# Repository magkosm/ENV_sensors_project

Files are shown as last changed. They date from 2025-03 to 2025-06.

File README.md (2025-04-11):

**Date**: 10/2024 - 01/2025  
**Author**: Robin GORIUS  
***Prelimenery Translations*** Michail Magkos
***PCB desing*** Enrique Hernando

These sensors were initially created to measure environmental variables in the Mars Desert Research Station in Utah for the CoreData set.  
As they are meant to be used by French students from future MDRS crews, a lot of documentation and code comments are in French.  

The development was done by Robin GORIUS over the course of 4 months. The sensors are far from perfect but could be considered as functioning prototypes for futur developpment.  
The main issue is the electrical assembly, which should be reduced to PCB soldering.  
Another improvement for easier use would be to shift the data exchange protocol from HTTP to MQTT and make the sensors go to sleep when not measuring.  
This change could enable the sensors to run on a battery for easier installation and integration with Home Assistant.  

sensor render

The sensors are equipped with 5 sensors and are able to measure the following variables:  

```
Temperature in °C  
Humidity in %  
Luminosity (Infrared, Visible, Total) in Lux  
Pressure in Pa  
CO2 levels in ppm  
VOC levels (unitless)  
```

The sensors are programmed to collect data every second and are asked by the collecting server to send their data every 30 seconds.  

The code for the sensor is quite versatile as it's written with well-separated classes.  
**WARNING**: Please note that the network manager implemented in the sensors isn't the most secure, as the SSIDs and passwords are stored directly in the ESP32 file system in a `.txt` file.  

The code for the collecting server is a bit messier, especially the part in charge of the graphs. This is due to the nature of the initial application not enabling the system to access online libraries.  

For further information on the use of the sensors, please check the user manual (French only for now, sorry!):  
[Manual](Manual/User_manual.pdf)  

Check out the CAD files in the [CAD folder](Mechanical_design/CAD/). Please note that the design was made with Fusion 360, and the `.step` file may present unwanted defects.  

The build information is briefly described in the [Build instructions](Electronics/Build_instructions.txt). The document is quite short but provides guidelines on how the assembly was designed. 

**Possible Future Implementations**:
- Add a Bluetooth scan to count nearby devices.

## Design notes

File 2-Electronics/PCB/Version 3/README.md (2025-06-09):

## 🔧 Update: Redone PCB Model

    I have redone the electrical scheme and PCB for be sure all is their place, also I done the routes in PCB manually because auto routes was doing weird things.

This corrected model replaces the previous version and ensures proper functionality according to the component datasheet and design guidelines.

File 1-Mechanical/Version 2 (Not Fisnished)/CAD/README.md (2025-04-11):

This CAD file its just for the top of the case, the bottom part its not the good one.
The finished version of the bottom its in .../Version 1/STL/Bottom.stl

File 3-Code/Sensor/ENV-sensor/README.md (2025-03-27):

# MDRS-ENV-sensors
Arduino code for the MDRS environnemental sensors

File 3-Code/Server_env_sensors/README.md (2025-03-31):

# MDRS-ENV-sensor-server
MDRS Environmental sensors collecting server code. 

This code collects, stores and displays measurements from the MDRS environmental sensors. Data is stored in an SQLite database and can be displayed on the dashboard or visualized with graphs. 

## Prerequisites
Before starting, make sure you have the following tools installed on your machine:
- [Python 3.x](https://www.python.org/downloads/)
- [Node.js](https://nodejs.org/en/) (which includes `npm` for managing JavaScript packages)
- [Git](https://git-scm.com/)

## 1. Installing the Python Virtual Environment

### Create a Virtual Environment

1. Clone the repository on your machine:
    ```bash
    git clone https://github.com/Robs2924/MDRS-ENV-sensor-server.git
    cd MDRS-ENV-sensor-server
    ```

2. Create a Python virtual environment:
    ```bash
    python -m venv .venv
    ```

3. Activate the virtual environment:
    - On **Windows**: 
    Open PowerShell in administrator mode outside of VSCode and type the command: 

     ```bash
      Set-Executionpolicy Unrestricted
      ```
      In the initial terminal in VSCode:

      ```bash
      .venv\Scripts\activate
      ```
    - On **macOS/Linux**:
      ```bash
      source .venv/bin/activate
      ```

### Install Python Dependencies

4. Install `pip` if not already done:
    ```bash
    python -m ensurepip --upgrade
    ```

5. Install the required Python dependencies for the project:
    ```bash
    pip install -r requirements.txt
    ```

## 2. Installing Webpack if you want to modify the graphs display part
### Install JavaScript Dependencies

1. Navigate to the project directory containing the `package.json` file (normally in `app/static/js` or another frontend-related directory).
   
2. If `npm` is not installed, you can install it via [Node.js](https://nodejs.org/en/) (npm is included with Node.js).

3. Install the JavaScript dependencies required by the project with npm:
    ```bash
    npm install
    ```

### Configure Webpack

4. If not already done, install Webpack and its dependencies in the project:
    ```bash
    npm install --save-dev webpack webpack-cli webpack-dev-server
    ```

5. Check that your Webpack configuration (`webpack.config.js`) is ready for the project. You can then compile your JavaScript files with the following command:
    ```bash
    npm run build
    ```

## 3. Launch the Project

### Launch the Flask Server

1. Make sure the virtual environment is activated and Python dependencies are installed.

2. Launch the Flask server with the following command:
    ```bash
    py server.py
    ```

The server should now be accessible at `http://127.0.0.1:5000`.

### Launch Webpack in Development Mode

1. If you want to launch Webpack in development mode with the development server (to watch changes in real-time), you can use the following command:
    ```bash
    npm run dev
    ```

This will launch Webpack Dev Server to serve your front-end application.

## 4. Troubleshooting

### Installation Problems

If you encounter errors while installing dependencies, make sure you have activated the Python virtual environment and installed all required dependencies with `pip install -r requirements.txt`.

If `npm` fails, make sure you have installed Node.js and are in the correct directory to execute npm commands.

### Permission Errors

If you get permission errors during installation, try running the commands with administrator rights (using `sudo` on macOS/Linux).

## Conclusion

Once these steps are completed, your project should be configured and ready to use, with a Python virtual environment to run the backend and Webpack to manage the frontend.

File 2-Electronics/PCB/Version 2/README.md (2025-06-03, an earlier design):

## 🔧 Update: Revised PCB Model

The previous version of the PCB had the following issues in the schematic and layout:

- Two decoupling capacitors were connected only to the VDD pin, leaving VDDH unpowered.
- A pull-up resistor between VDD and 3.3V was missing, which is required for proper operation.
- PCB routing was not optimal and needed to be revised to accommodate the above corrections.

These issues have been addressed in the new version:

- VDDH is now correctly powered via decoupling capacitors.
- A pull-up resistor has been added between VDD and 3.3V.
- The PCB layout has been completely re-routed to reflect the updated schematic.

This corrected model replaces the previous version and ensures proper functionality according to the component datasheet and design guidelines.

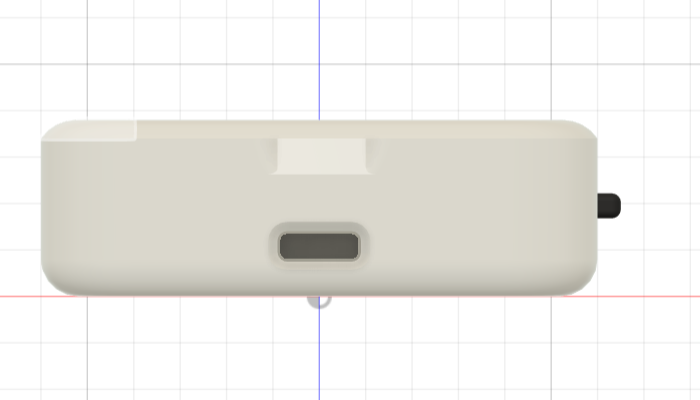
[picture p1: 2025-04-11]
1-Mechanical/Version 1/IMG/Front.PNG

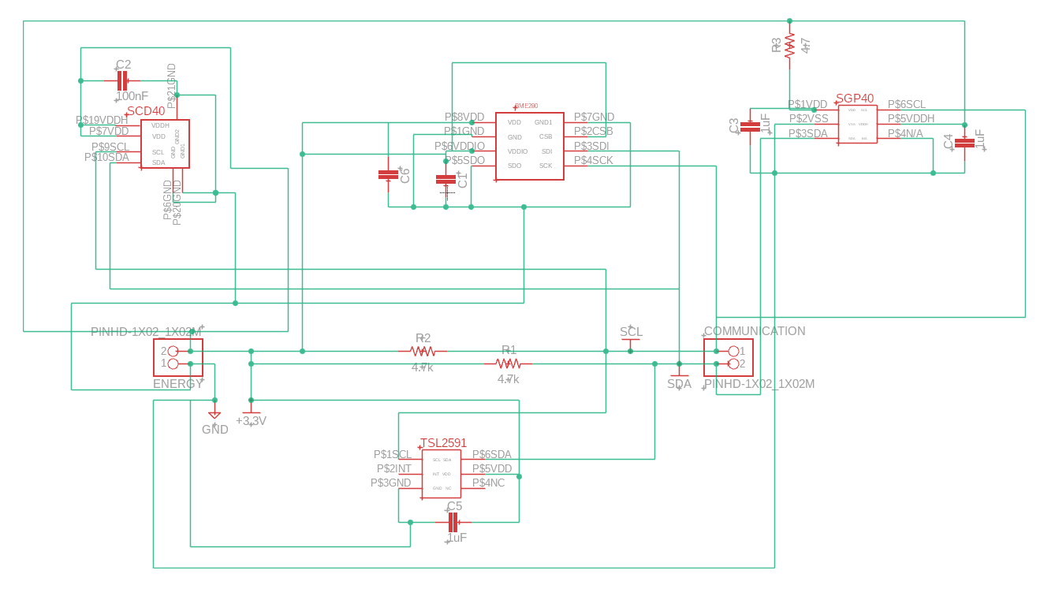
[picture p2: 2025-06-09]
2-Electronics/PCB/Version 3/Images/Electrical Scheme.PNG

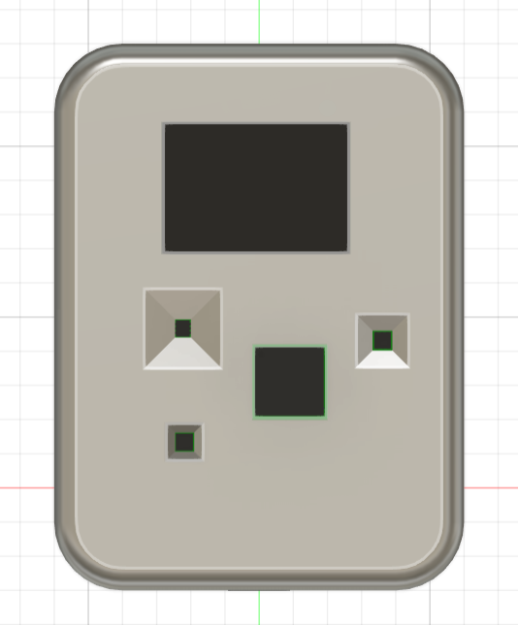
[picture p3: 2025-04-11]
1-Mechanical/Version 2 (Not Fisnished)/IMG/Up.PNG

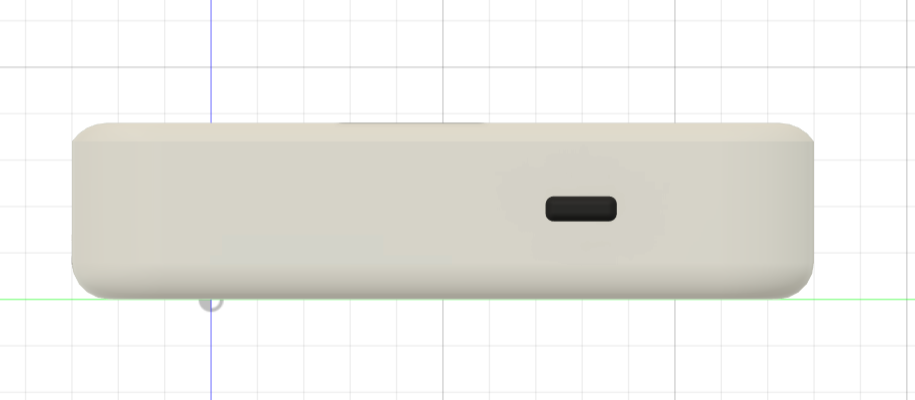
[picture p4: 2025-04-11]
1-Mechanical/Version 1/IMG/Right.PNG

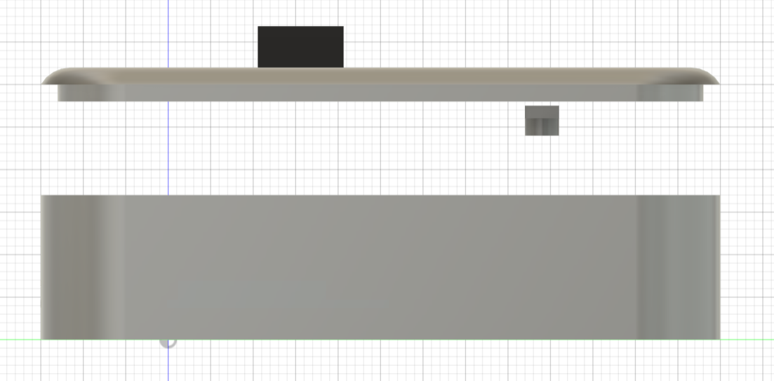
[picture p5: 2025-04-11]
1-Mechanical/Version 2 (Not Fisnished)/IMG/Right.PNG

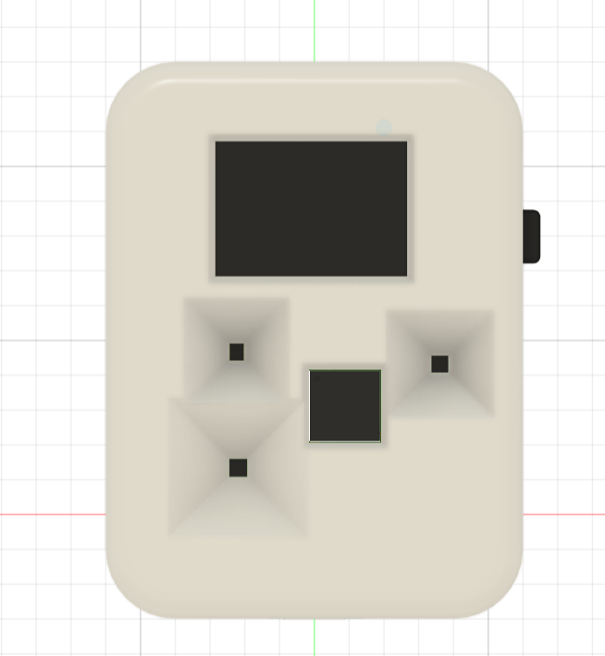
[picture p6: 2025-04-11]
1-Mechanical/Version 1/IMG/Up.PNG

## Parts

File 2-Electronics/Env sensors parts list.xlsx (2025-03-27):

Name | Aliexpress lot price | Qte per lot | Qte per sensor | Price per sensor | Link
TSL2591 | 3.69 € | 1 | 1 | 3.69 € | https://fr.aliexpress.com/item/1005006864126085.html?mp=1
SSD1306 128x32 oled | 1.67 € | 1 | 1 | 1.67 € | https://fr.aliexpress.com/item/32794209149.html?mp=1
ESP32 D1 mini | 3.79 € | 1 | 1 | 3.79 € | https://fr.aliexpress.com/item/1005006400668971.html?mp=1
USB A socket | 1.60 € | 10 | 1 | 0.16 € | https://fr.aliexpress.com/item/1005006092762066.html?mp=1
BME280-3,3 | 2.69 € | 1 | 1 | 2.69 € | https://fr.aliexpress.com/item/1005004527984343.html?mp=1
SGP40 | 6.79 € | 1 | 1 | 6.79 € | https://fr.aliexpress.com/item/1005001847634823.html?mp=1
M2-12 screws | 1.75 € | 100 | 2 | 0.04 € | https://fr.aliexpress.com/item/1005005480125500.html?mp=1
M2-5 screws | 1.51 € | 100 | 7 | 0.11 € | https://fr.aliexpress.com/item/1005005480125500.html?mp=1
SCD40 | 17.29 € | 1 | 1 | 17.29 € | https://fr.aliexpress.com/item/1005004221715765.html?mp=1
Cost per sensor | 36.22 €
Shipping time | < 10 days (nov 26 -28)

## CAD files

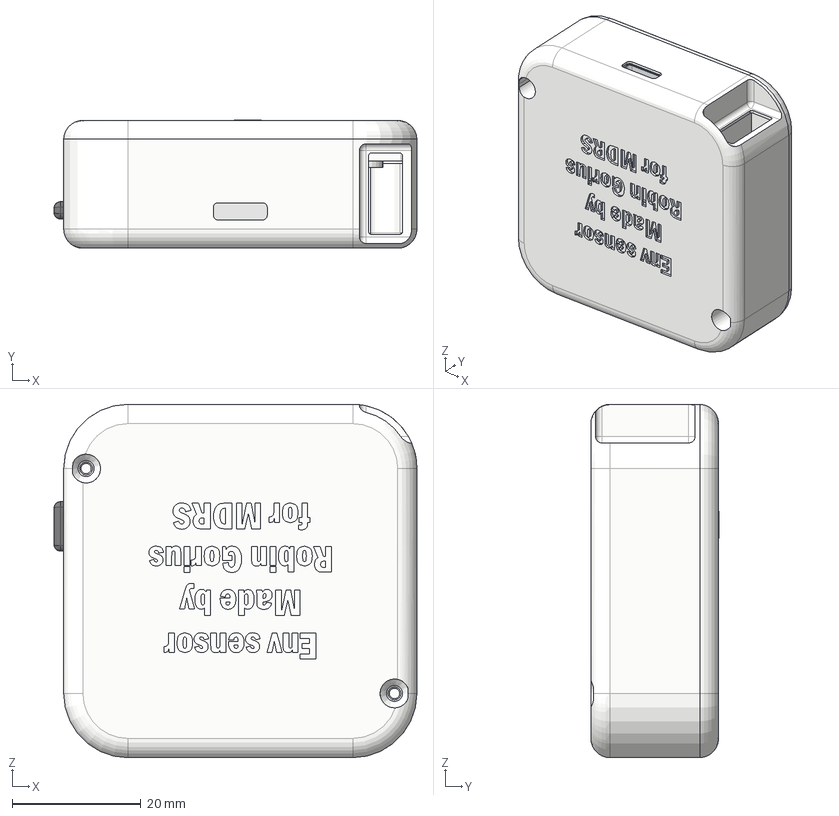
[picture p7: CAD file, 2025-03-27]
1-Mechanical/CAD/Capteur_environnementaux_MDRS v32.step
56.5 x 20.0 x 55.0 mm
Esp32
Oled
SCD40
SGP40
BME280
TSL2591
top
main
Bnt
Lock plate scd
lock plate oled

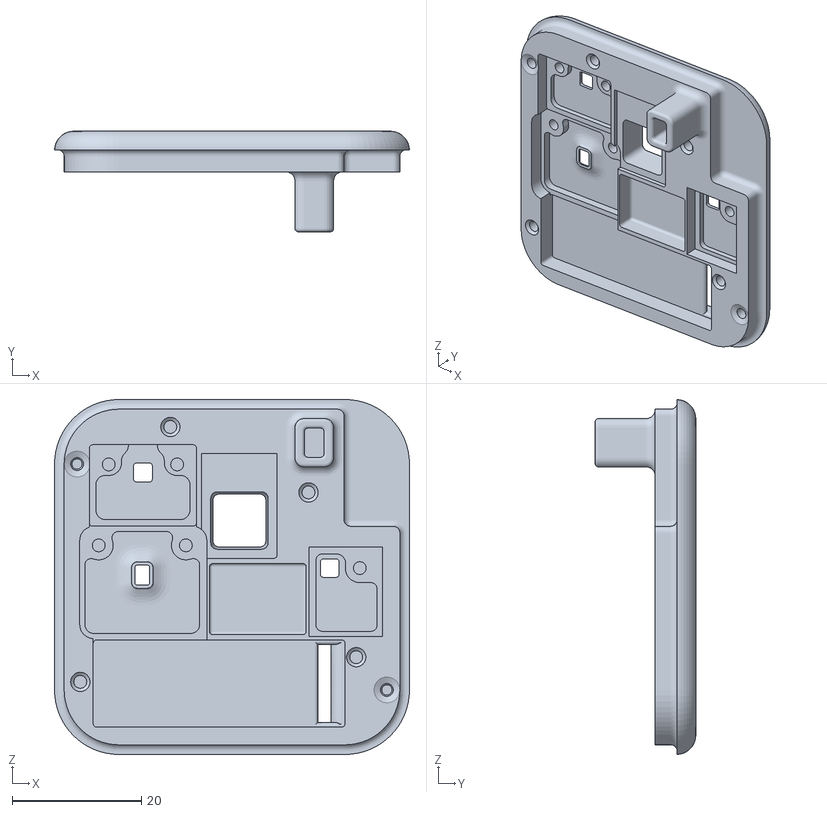
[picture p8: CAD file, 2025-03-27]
1-Mechanical/STL/Top.stl
55.0 x 15.6 x 55.0

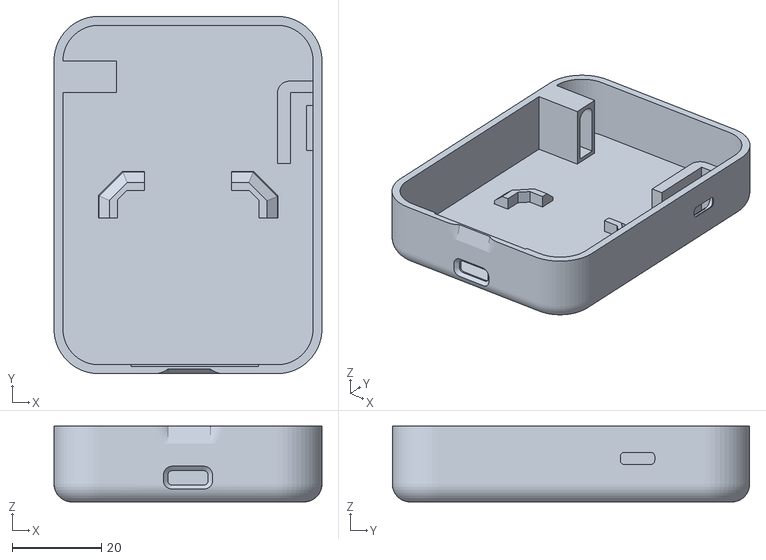
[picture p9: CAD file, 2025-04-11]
1-Mechanical/Version 1/STL/Bottom.stl
60.0 x 80.0 x 17.0

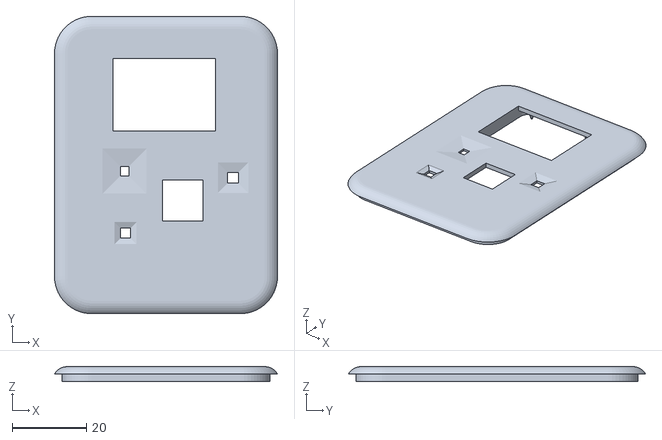
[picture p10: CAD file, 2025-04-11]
1-Mechanical/Version 2 (Not Fisnished)/STL/Top V2.stl
60.0 x 80.0 x 4.00

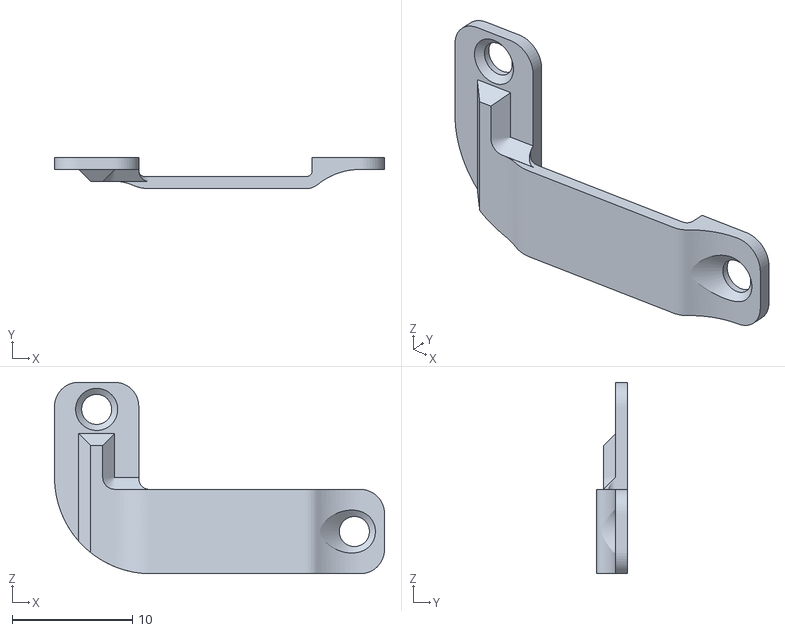
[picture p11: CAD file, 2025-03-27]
1-Mechanical/STL/Lock_plate_scd.stl
27.4 x 2.60 x 15.9

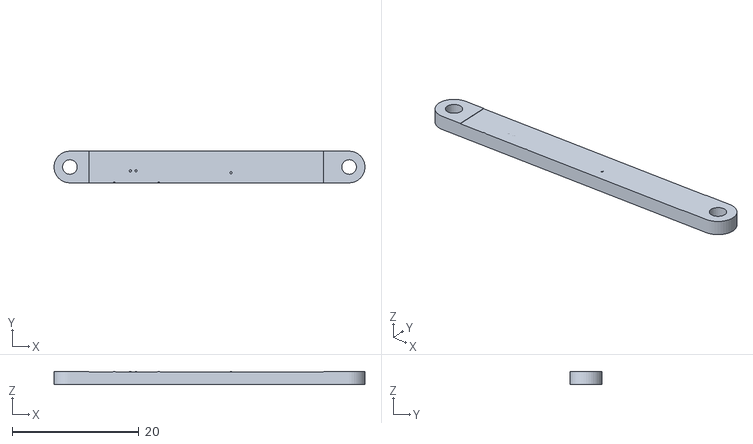
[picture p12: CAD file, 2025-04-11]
1-Mechanical/Version 1/STL/Lock Plate PCB.stl
49.0 x 5.00 x 2.00

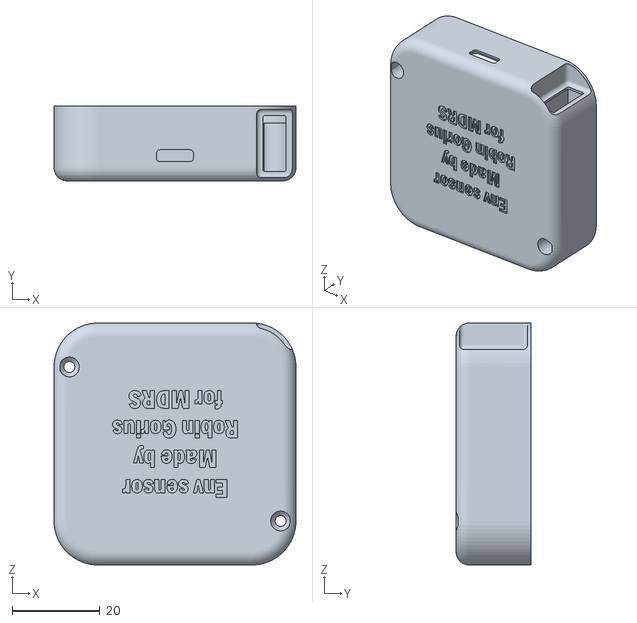
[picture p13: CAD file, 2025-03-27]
1-Mechanical/STL/Bottom.stl
55.0 x 17.0 x 55.0

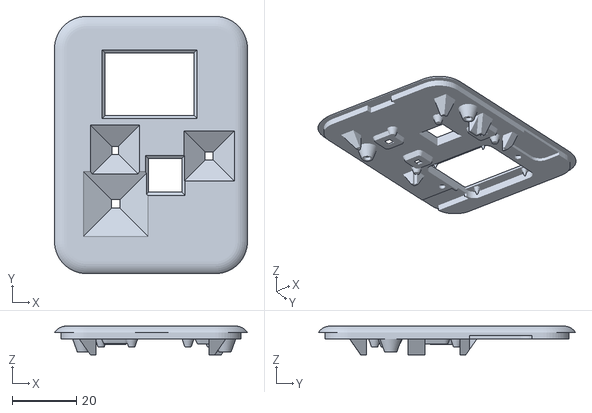
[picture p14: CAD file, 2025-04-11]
1-Mechanical/Version 1/STL/Top.stl
60.0 x 80.0 x 9.00

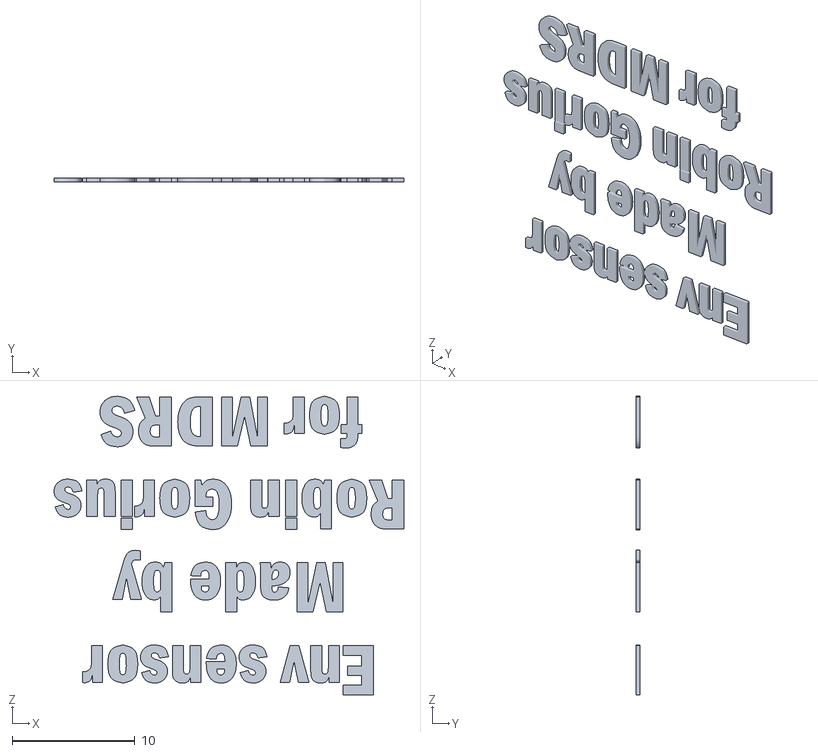
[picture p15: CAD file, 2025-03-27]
1-Mechanical/STL/Txt.stl
28.5 x 0.3 x 24.3

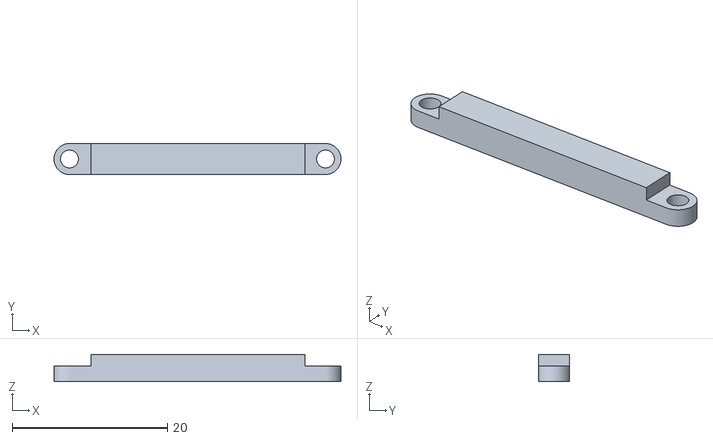
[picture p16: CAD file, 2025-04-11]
1-Mechanical/Version 1/STL/Lock Plate Display.stl
37.0 x 4.00 x 3.50

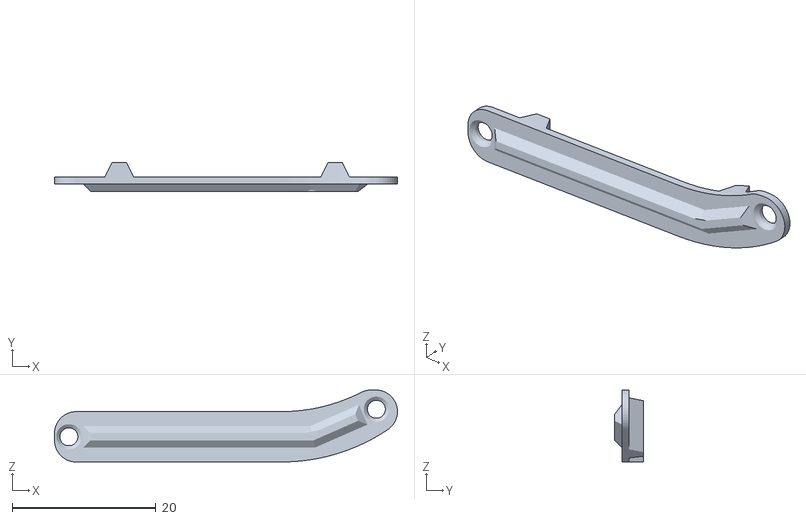
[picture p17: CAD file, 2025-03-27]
1-Mechanical/STL/Lock_plate_oled.stl
47.7 x 4.00 x 10.0

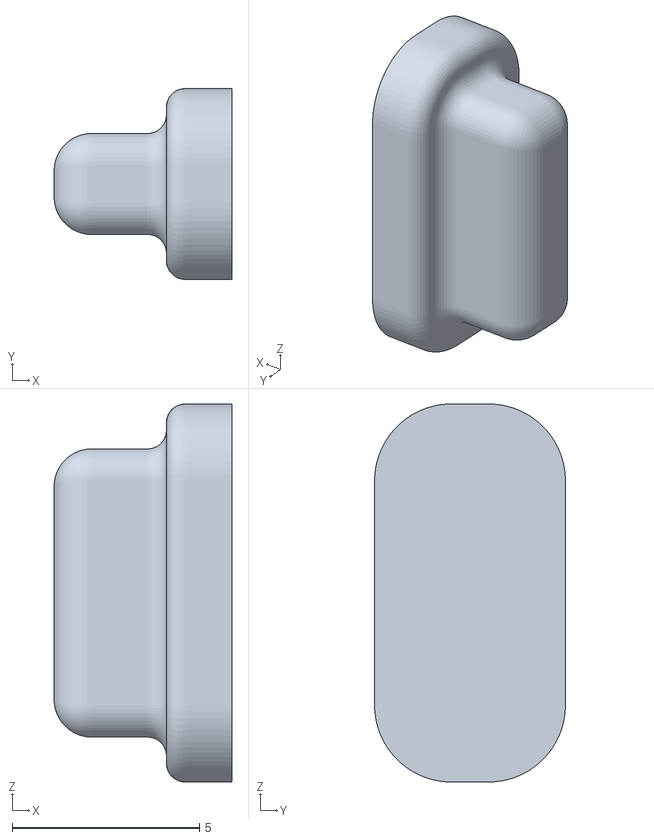
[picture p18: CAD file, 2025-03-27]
1-Mechanical/STL/Bnt.stl
4.75 x 5.10 x 10.1

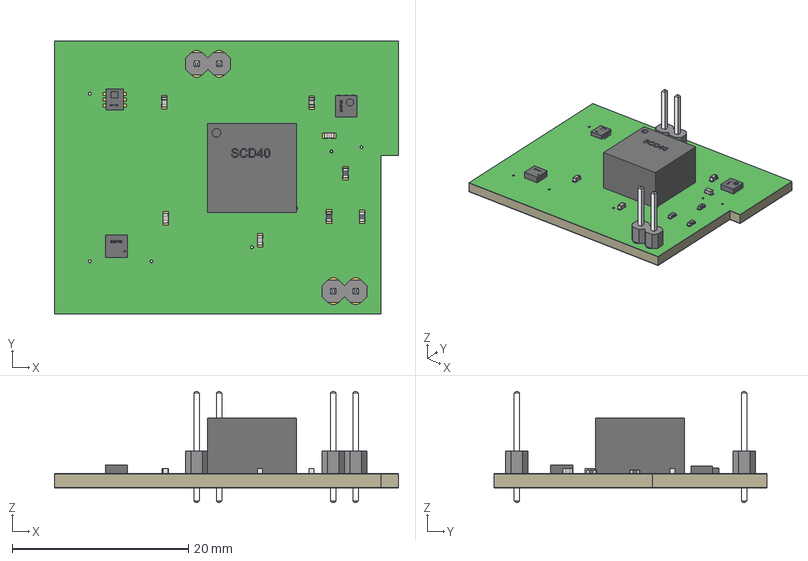
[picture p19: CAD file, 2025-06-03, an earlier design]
2-Electronics/PCB/Version 2/Fusion Files/3D Model.step
39.0 x 31.0 x 12.6 mm
Placa
1-copper
16-copper
1-soldermask
16-soldermask
RESC1005X40 x 3
BME280
SCD40
TSL2591
1X02 x 2
CAPC1005X60 x 5
SGP40

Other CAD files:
2-Electronics/PCB/Version 1/Fusion Files/3D Model.f3d
2-Electronics/PCB/Version 1/Fusion Files/PCB Project.f3z
2-Electronics/PCB/Version 2/Fusion Files/3D Model.f3d
2-Electronics/PCB/Version 2/Fusion Files/PCB Project.f3z
2-Electronics/PCB/Version 3/Fusion Files/PCB Project.f3z

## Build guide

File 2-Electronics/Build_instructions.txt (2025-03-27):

ENV sensor build instructions :

This short document give guidlines on how to build and assembke the ENV sensors.
Theses sensors are easy to assemble but the wiring can be a bit tricky and repetitive to do. 
As a futur improvment I may suggest to create a dedicated pcb. I didn't perceived this way to enable futur students to easily replace a module in case a sensor broke up.
Further more the commonly available 2.54mm dupont connector were to big to be used to connect the sensors to the esp32.

Parts list for one sensor:

1x TSL2591	                	
1x SSD1306 128x32 oled	
1x ESP32 D1 mini	        	
1x USB A socket	        
1x BME280-3,3	        	
1x SGP40	                	
2x M2-12 screws	        	
9x M2-5 screws	    	
1x SCD40	            	
1x Push button
1x 4x1 2.54mm dupont connector (male and female)
1x 6x4 holes perf board

You will also need 24 and 28 AWG wire for the electrical connexions, heat shrink and double sided tape.						

3D prints for one sensor :

- Bottom.stl
- Top.stl
- Bnt.stl
- Lock_plate_oled.stl
- Lock_plate_scd.stl

For the print settings, Nothing special :
- 2 perimeters
- 20% infil
- support for the Bottom and Lock plates

Electrical wiring :

1 - We will start by creating the central I2C bus distribution pcb.
For that we will need the perf board and the 28 AWG wire.

Start by cutting a piece of perf board that has 4 by 6 holes. You may have to file the sides to make it fit in the top part of the enclosure.
Cut 6 sets of 4 wire of about 50mm
You can twist each set for an easier manipulation.
Solder each wire to on hole in the perf board. Use one color wire per row.
Once all the wire are soldered on the perf board, join all the point in a row together using solder bridges. 

2 - Wire trimming

Assemble the sensors and the screen in their corresponding emplacement. Secure them with the screws. 
WARNING Don't tighthen to much the screws ont he sgp40, the enclosure wall are really thin and you may create a hole.

Once every sensor is in place, put the pcb you just created in it's emplacement. Then start cutting the wires to the right lenght. 
Before hand choose a color for the 4 pins of each sensors:

-GND
-VCC (3.3 v !!!)
-SCL
-SDA

Be sure to match the color with the label on each I2C devices !

Also prepare wires to go between the ESP32 and the dupont connector.

3 - Soldering

Once all the wire are cut to size you can solder them to the corresponding pcb pads.
Also solder the wires to the duponts connectors.

Here is the correspondance between ESP32 pins and I2C lines :

-GND --> GND
-VCC --> 3V3
-SCL --> IO22
-SDA --> IO21

WARNING : Make sure to plug the dupont connector in the right way, I would recommand to mark the two halves with correction fluid.

You can also wire the USB-A port to the ESP32. I would recommend to check the port pinout before soldering it.
As of today the data lines of the usb port aren't used but it could be nice to wire them as we can enable this functionnality in software.

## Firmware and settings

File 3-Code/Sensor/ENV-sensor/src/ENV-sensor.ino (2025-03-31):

/*
This code operates the environmental sensors designed for the MDRS.
These sensors measure the following variables:
-Temperature
-Humidity
-Pressure
-CO2 concentration
-VOC index
-Luminosity

@Author : Robin Gorius
@Date : 12/24
*/

#include <Arduino.h>
#include <SPIFFS.h>
#include <ESPmDNS.h>
#include <Wire.h>
#include <HTTPClient.h>
#include <ArduinoJson.h>

#include "Sensors.h"
#include "Display.h"
#include "ConfigWifi.h"
#include "ConfigServer.h"

#define BUTTON_PIN 18
#define LED_PIN 2
 
Display display;
Sensors sensors(&display, 7, 0, 0, 0, 0);//class that manages all sensors
ConfigWifi SPIFFSWifi;//class that manages internal storage and wifi connection from internal storage
ConfigServer server(&sensors, &SPIFFSWifi, 80);//class that manages the configuration server

volatile unsigned long lastDisplayChange = 0;
const unsigned long debounceDelay = 200;  // Debounce delay in milliseconds
volatile int buttonPresses = 0;
volatile int displaysNumber = 5;
unsigned long last_read = 0;//time of the last sensor read
boolean dispOK = true;//flag to know if displaying measurements is available
//bool sensorStatus = true;

void IRAM_ATTR changeDisplay() {
  unsigned long currentMillis = millis();
  // Debounce
  if (currentMillis - lastDisplayChange > debounceDelay) {
    lastDisplayChange = currentMillis;
    buttonPresses++;
    sensors.index = buttonPresses % displaysNumber;
    //Serial.println("Button pressed, new display mode: " + String(sensors.index));
  }
}

void displayNetInfos(int index){
  switch(index){
    
    case 0:
    display.disp2Lines("Sensor name", SPIFFSWifi.nomCapteur, 2,2);
    break;

    case 1:
    display.disp2Lines("Mode : ", SPIFFSWifi.wifiStatString(SPIFFSWifi.WifiMode),2, 2);
    break;

    case 2:
    if(SPIFFSWifi.WifiMode == 1){
      display.disp2Lines("Network :", WiFi.SSID() ,2, 1);
    }
    else if(SPIFFSWifi.WifiMode == 2){
      display.disp2Lines("AP SSID :", WiFi.softAPSSID() ,2, 1);
    }
   
    break;

    case 3:
    if(SPIFFSWifi.WifiMode == 2){//if the condition is not met, the program automatically continues (Warning message "statement may fall through" at compilation is normal)
      display.disp2Lines("AP Pass :", SPIFFSWifi.ApPass ,2, 1);
      break;
    }
    else{
      displayNetInfos(4);
    }
    break;

    case 4:
    if(SPIFFSWifi.WifiMode == 1){
      display.disp2Lines("Network IP :", WiFi.localIP(), 2, 1);
    }

    else if(SPIFFSWifi.WifiMode == 2){
      display.disp2Lines("Local IP :", WiFi.softAPIP(), 2, 1);
    }

    else{
      display.disp2Lines("No Local IP", "Not connected", 2, 1);
    }

    break;

  }
}

void displayInfos(int index){

  switch(index){
    
    case 0:
    displayNetInfos(0);
    break;

    case 1:
    displayNetInfos(1);
    break;

    case 2:
    displayNetInfos(2);
    break;

    case 3:
    displayNetInfos(3);
    break;

    case 4:
    displayNetInfos(4);
    break;

  }
}

void setup() {

  Serial.begin(115200);

  if (!display.begin()) {
    Serial.println(F("SSD1306 fail to init"));
  }
  display.disp2Lines("    MDRS", "Env sensor", 2, 2);
  delay(1500);

  // Initialize sensors
  sensors.begin();
  sensors.readSensors();

  pinMode(2, OUTPUT);
  pinMode(BUTTON_PIN, INPUT_PULLUP);  // Declare button pin as input
  attachInterrupt(digitalPinToInterrupt(BUTTON_PIN), changeDisplay, FALLING);  // Trigger on button press (low level)
  
  SPIFFSWifi.begin();//start SPIFFS, check if default files exist and create them if not
  SPIFFSWifi.printSPIFFS();
  
  display.clearDisplay();
  display.disp2Lines("Testing", "connections", 2, 2);
  delay(1500);

  Serial.println("Trying to connect to a known wifi");
  if(SPIFFSWifi.StationConnect()){//trying to connect to a known network
    Serial.println("Connection to a known network succeeded");
    for(int i = 0; i < 5; i++){
      digitalWrite(2, HIGH);
      delay(100);
      digitalWrite(2, LOW);
      delay(100);
    } 
  }
  //If connection fails or if no network is saved, start in AP mode
  else{//if the connection to a known network fails, create an AP
    Serial.println("No network saved or connection failed.");
    Serial.println("Starting in AP mode");
    Serial.println("Creating access point");
    dispOK = SPIFFSWifi.APConnect(); 
    
    displayInfos(sensors.index);//display the right info according to the index
  }  

  //Configure and start the captive server
  server.startConfigServer();// create the web route and start server
  last_read = millis();//save the starting time to measure time between readings

  // Set up built-in LED (optional)
  pinMode(LED_PIN, OUTPUT);  // Set the pin as output
  digitalWrite(LED_PIN, HIGH);  // Turn on LED to indicate successful setup
}

void loop() {
  if(SPIFFSWifi.WifiMode == 1){//at each loop check if we're still connected to a local network
    if(WiFi.status() != WL_CONNECTED){//connection lost
      Serial.println("Wifi connection lost");
      SPIFFSWifi.WifiMode = 0;//no connection
      dispOK = SPIFFSWifi.APConnect();
      displayInfos(sensors.index);
    }
  }

  if(server.getConnecting()){//if we received a connection request for a new network on the server
    delay(3000);
    Serial.println("ESP will reset for new connection");
    ESP.restart();
  }
  
  if(millis() - sensors.last_disp > 1000){
    sensors.last_disp = millis();

    if(sensors.index >= 0 && sensors.index <= 4)
    {
      displayInfos(sensors.index);
    }
    else{//if index is out of range, display measurements
      if(dispOK){
        sensors.displayMeasurements();
      }
      else{
        display.clearDisplay();
      }
    }   
  }

  if(millis() - last_read > 3000){//read sensors
    sensors.readSensors();
    last_read = millis();
  }
  
  //if 60s passed without sending the data, reset min, max and average
  if((millis() - server.getLast_send() )> 60000){//reset min, max and avg if a minute passes without sending data
    Serial.println("Resetting min, max and average as no server asked for data");
    sensors.getTemperature().reset();
    sensors.getHumidity().reset();
    sensors.getPressure().reset();
    sensors.getCO2().reset();
    sensors.getIR().reset();
    sensors.getVisibleLuminosity().reset();
    sensors.getFullLuminosity().reset();
    sensors.getLux().reset();
    sensors.getVocIndex().reset();
    sensors.getSraw().reset();
    server.setLast_send(millis());
  }
}

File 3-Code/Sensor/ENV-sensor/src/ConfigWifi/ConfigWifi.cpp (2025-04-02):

#include "ConfigWifi.h"

bool ConfigWifi::begin(){

  nomCapteur = "";
  ApPass = "";
  ApName ="";
  WifiMode = 0;

  Serial.println("setting Wifi Mode to 0 in configWifi begin");

  if (!SPIFFS.begin(true)) {
    Serial.println("Error mounting SPIFFS");
    return false;
  }
  else{
    // Check if the file exists
    if (SPIFFS.exists("/Config/Config.csv")) {
      Serial.println("Config file exist");
    } 
    else {
      Serial.println("Config file does not exist, creating");
      writeConfigFile("Sensor", "#MDRS311sensors!", "Sensor");//ssid, mdp, default name
    }

  }

  return true;
}

bool ConfigWifi::failToConnect() {
  unsigned long start = millis();
  while (WiFi.status() != WL_CONNECTED) {//non-blocking operation because the ESP has 2 cores
    delay(500);
    Serial.print(".");

    if ((millis() - start) > 40000) {
      Serial.println("Connexion failed");
      return true;
    }
  }
  return false;
}

bool ConfigWifi::writeNetworkInfoToSPIFFS(String ssid, String pass, String secu, String user, bool connected) {
  /*
  Add the network info to the file system. This function assume that the esp is connected to the SSID wifi if connected is set to true
  the file stucture is:
  Name : SSID.txt
  Content:
  SSID
  Secu type
  user (if secu == WPA2_Entreprise)
  PASS
  IP
  Gateway IP
  Subnet mask
  fails
  */

  IPAddress Ip;
  IPAddress defaultGateway;
  IPAddress maskSubnet;

  if(connected){
    Ip = WiFi.localIP();
    defaultGateway = WiFi.gatewayIP();
    maskSubnet = WiFi.subnetMask();
  }

  if (!SPIFFS.begin(true)) {
    Serial.println("An Error has occurred while mounting SPIFFS");
    return false;
  }

  File file = SPIFFS.open("/Networks/" + ssid + ".txt", FILE_WRITE);

  if (!file) {
    Serial.println("Failed to open file for writing");
    file.close();
    return false;  // Sortie de la fonction ici
  }

  if (file.println(ssid)) {
    Serial.println("writting down network infos");
    if(connected){
      Serial.print("-Ip written : ");
      Serial.println(Ip.toString());
      Serial.print("--Gateway written : ");
      Serial.println(defaultGateway.toString());
      Serial.print("---Subnet mask written : ");
      Serial.println(maskSubnet.toString());
    }
    file.println(secu);
    if(secu == "WPA2_Enterprise"){
      file.println(user);
      Serial.println("USER WRITTEN");
    }
    file.println(pass);
    if(connected){
      file.println(Ip.toString());
      file.println(defaultGateway.toString());
      file.println(maskSubnet.toString());
      file.println(0);  //failure count, if connected = 0
    }
    else{
      file.println(-1);  //static ip
      file.println(-1);  //default gateway
      file.println(-1);  //subnetmask
      file.println(-1);  //fail counter
    }
    file.close();
  } else {
      file.close();
      Serial.println("Fail to write");
    return false;
  }

  //Serial.println("----------------------------");
  return true;
}

bool ConfigWifi::deleteNetwork(String SSID){

  if(SPIFFS.remove("/Networks" + SSID + ".txt")){
    return true;
  }
  else{
    return false;
  }

}

JsonDocument ConfigWifi::loadNetworks(){
  JsonDocument jsonResponse;

  /*
      Read the network infos from the file SSID.txt (already exist)
      Recover :
      -SSID
      -secu type
      -user id (if needed)
      -Password
      -Static IP
      -Default gateway IP
      -Subnet mask 
      -failures

      Configure the wifi with this infos
      Connect to the wifi
      */
  String Rssid = "";
  String Rsecu = "";
  String Ruser = "";
  String Rpass = "";
  String RIp = "";
  String RdefaultGateway = "";
  String RmaskSubnet = "";

  Serial.println("Loading networks from SPIFFS...");

  File root = SPIFFS.open("/Networks");

  if (!root || !root.isDirectory()) {
    Serial.println("fail to open root");
    jsonResponse["s"] = "error";
    return jsonResponse;
  }

  File file = root.openNextFile();
  String fname;

  while (file) {
    yield();  // Allow WDT to reset

    fname = file.name();
    if (fname.endsWith(".txt")) {

      Rssid = file.readStringUntil('\n');
      Rsecu = file.readStringUntil('\n');

      Rsecu.remove(Rsecu.length() - 1);  //remove /n

      if (Rsecu == "WPA2_Entreprise") {  //if we need an identifier
        Ruser = file.readStringUntil('\n');
      }

      Rpass = file.readStringUntil('\n');
      RIp = file.readStringUntil('\n');
      RdefaultGateway = file.readStringUntil('\n');
      RmaskSubnet = file.readStringUntil('\n');

      Rssid.remove(Rssid.length() - 1);
      Rpass.remove(Rpass.length() - 1);
      Ruser.remove(Ruser.length() - 1);
      RIp.remove(RIp.length() - 1);  //remove \n character
      RdefaultGateway.remove(RdefaultGateway.length() - 1);
      RmaskSubnet.remove(RmaskSubnet.length() - 1);

      JsonObject networkInfo = jsonResponse[Rssid].to<JsonObject>();;
      networkInfo["Pass"] = Rpass;
      networkInfo["SECU_TYPE"] = Rsecu;
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

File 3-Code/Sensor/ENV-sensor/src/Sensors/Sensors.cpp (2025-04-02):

#include "Sensors.h"

Sensors::Sensors(Display* oledDisplay, float dt, float dh, float dp, float dco, float dvoc) :
  display(oledDisplay),
  temp("Temperature", dt),
  hum("Humidity", dh),
  pres("Pressure", dp),
  alt("Altitude", 0.0),
  CO2("CO2", dco),
  IR("IR", 0.0),
  Full("Full", 0.0),
  Visible("Visible", 0.0),
  lux("Lux", 0.0),
  sraw("Raw_VOC", 0.0),
  Voc_Index("VOC Index", dvoc)
{
  Serial.println(F("Sensors class created"));
}

void Sensors::begin() {
  Wire.begin();

  if (!bme.begin(BME280_ADDR)) {
    Serial.println("BME280 fail to init");
  } else {
    getBMEValues(temp.newVal, pres.newVal, hum.newVal, alt.newVal);
  }

  if (!SCD40.begin()) {
    Serial.println("SCD40 fail to init");
  } else {
    calibrateSCD40(SCD40, 5, alt.newVal, pres.newVal);
  }

  if (!tsl.begin()) {
    Serial.println(F("TSL2591 fail to init"));
  }

  if (!sgp.begin()) {
    Serial.println("SGP40 fail to init");
  }
}

Grandeur& Sensors::getTemperature() { 
  return temp; 
}
Grandeur& Sensors::getHumidity() { 
  return hum; 
}
Grandeur& Sensors::getPressure() { 
  return pres; 
}
Grandeur& Sensors::getAltitude() { 
  return alt; 
}
Grandeur& Sensors::getCO2() { 
  return CO2; 
}
Grandeur& Sensors::getIR() { 
  return IR; 
}
Grandeur& Sensors::getFullLuminosity() { 
  return Full; 
}
Grandeur& Sensors::getVisibleLuminosity() { 
  return Visible; 
}
Grandeur& Sensors::getLux() { 
  return lux; 
}
Grandeur& Sensors::getSraw() { 
  return sraw; 
}
Grandeur& Sensors::getVocIndex() { 
  return Voc_Index; 
}

void Sensors::readSensors() {
  getBMEValues(temp.newVal, pres.newVal, hum.newVal, alt.newVal);
  getSGPValues(temp.newVal, hum.newVal, sraw.newVal, Voc_Index.newVal);
  getTSLValues(IR.newVal, Full.newVal, Visible.newVal, lux.newVal);

  if(getSCDValues(CO2.newVal)){
    CO2.update();
  }

  temp.update();
  hum.update();
  pres.update();
  alt.update();
  sraw.update();
  Voc_Index.update();
  IR.update();
  Full.update();
  Visible.update();
  lux.update();
}

void Sensors::displayMeasurements() {
  // Define which measurement to display based on index
  const char* names[] = {"Temperature", "Humidity", "Pressure", "Altitude", "CO2 level", "Luminosity", "VOC Index"};
  
  switch (index % 7) {
    case 0: // Temperature & Humidity
      display->clearDisplay();
      displayMeasurement("Temperature", temp.getLastVal(), "C", 2);
      displayMeasurement("Humidity", hum.getLastVal(), "%", 2, 16);
      break;
    
    case 1: // Pressure & Altitude
      display->clearDisplay();
      displayMeasurement("Pressure", pres.getLastVal() / 100.0, "hPa", 2);  // Convert Pa to hPa
      displayMeasurement("Altitude", alt.getLastVal(), "m", 2, 16);
      break;
    
    case 2: // CO2
      display->clearDisplay();
      displayMeasurement("CO2", CO2.getLastVal(), "ppm", 2);
      break;
    
    case 3: // VOC
      display->clearDisplay();
      displayMeasurement("VOC Index", Voc_Index.getLastVal(), "", 2);
      displayMeasurement("Raw VOC", sraw.getLastVal(), "", 2, 16);
      break;
    
    case 4: // Lux
      display->clearDisplay();
      displayMeasurement("Luminosity", lux.getLastVal(), "lx", 2);
      break;
    
    case 5: // Luminosity components
      display->clearDisplay();
      displayMeasurement("Full", Full.getLastVal(), "c", 2);
      displayMeasurement("IR", IR.getLastVal(), "c", 2, 16);
      break;
    
    case 6: // Visible
      display->clearDisplay();
      displayMeasurement("Visible", Visible.getLastVal(), "c", 2);
      break;
  }
}

void Sensors::getTSLValues(float &ir, float &full, float &visible, float &lux) {
  uint32_t lum = tsl.getFullLuminosity();
  ir = lum >> 16;
  full = lum & 0xFFFF;

  if (full == 37888) {
    tsl.setGain(TSL2591_GAIN_LOW);
    lum = tsl.getFullLuminosity();
    ir = lum >> 16;
    full = lum & 0xFFFF;
  }

  if (full < 100) {
    if (tsl.getGain() == TSL2591_GAIN_LOW) {
      tsl.setGain(TSL2591_GAIN_MED);
    } else if (tsl.getGain() == TSL2591_GAIN_MED) {
      tsl.setGain(TSL2591_GAIN_HIGH);
    }
    lum = tsl.getFullLuminosity();
    ir = lum >> 16;
    full = lum & 0xFFFF;
  }

  if (full > 37888 - 100) {
    if (tsl.getGain() == TSL2591_GAIN_HIGH) {
      tsl.setGain(TSL2591_GAIN_MED);
    } else if (tsl.getGain() == TSL2591_GAIN_MED) {
      tsl.setGain(TSL2591_GAIN_LOW);
    }
    lum = tsl.getFullLuminosity();
    ir = lum >> 16;
    full = lum & 0xFFFF;
  }

  visible = full - ir;
  lux = tsl.calculateLux(full, ir);
}

bool Sensors::calibrateSCD40(SCD4x &sensor, float tempOffset, float sensorAltitude, float ambientPressure) {
  if (!sensor.stopPeriodicMeasurement()) return false;
  if (!sensor.setTemperatureOffset(tempOffset)) return false;
  if (!sensor.setSensorAltitude(sensorAltitude)) return false;
  if (!sensor.setAmbientPressure(ambientPressure)) return false;
  if (!sensor.persistSettings()) return false;
  if (!sensor.startPeriodicMeasurement()) return false;
  return true;
}

bool Sensors::getSCDValues(float &co2) {
  if (SCD40.readMeasurement()) {
    co2 = SCD40.getCO2();
    return true;
  } 
  else {
    co2 = -1;
    return false;
  }
}

void Sensors::getBMEValues(float &t, float &p, float &h, float &a, float seaLevel) {
  t = bme.readTemperature();
  p = bme.readPressure();
  h = bme.readHumidity();
  a = bme.readAltitude(seaLevel);
}

void Sensors::getSGPValues(float t, float h, float &sraw, float &voc_index) {
  sraw = sgp.measureRaw(t, h);
  voc_index = sgp.measureVocIndex(t, h);
}

void Sensors::afficheGrandeur(String grandeur, float valeur, String unite, int space) {
    display->clearDisplay();
    display->setTextSize(2);
    display->setTextColor(SSD1306_WHITE);

    // Display size with truncation if necessary
    display->drawTruncatedText(grandeur, 128, 0, 0);

    // Calculating position for value
    int x = 0;
    display->setCursor(x, 17);
    display->print(valeur, 2);

    // Get the dimensions of the displayed value
    int16_t x1, y1;
    uint16_t textWidth, textHeight;
    display->getTextBounds(String(valeur).c_str(), x, 17, &x1, &y1, &textWidth, &textHeight);

    // Unit position with spacing
    x += textWidth + space;

    // Display unit with truncation if necessary
    display->drawTruncatedText(unite, 128, x, 17);

    // Show screen
    display->display();
}

void Sensors::printTSLValues() {
    Serial.println("--> TSL2591 Reading:");
    IR.print();
    Full.print();
    Visible.print();
    lux.print();
    Serial.println();
}

void Sensors::printSCDValues() {
    Serial.println("--> SCD40 Reading:");
    CO2.print();
    Serial.println();
}

void Sensors::printBMEValues() {
    Serial.println("--> BME280 Reading:");
    temp.print();
    pres.print();
    hum.print();
    alt.print();

    Serial.println();
}

void Sensors::printSGPValues() {
    Serial.println("--> SGP40 Reading:");
    sraw.print();
    Voc_Index.print();
    Serial.println();
}

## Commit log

2025-04-02 Changed repo folders names
    [Bnt.stl, Bottom.stl, Capteur_environnementaux_MDRS v32.step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]
2025-04-02 Changed the fusion cad file
2025-04-04 Add initial schematic, reference image, and custom sensor library (BME280, SCD4X, SGP40, TSL2591). Enrique Hernando
2025-04-04 PCB v1.0 finalized – includes full schematic and board layout. Enrique Hernando
    [3D Model.f3d, PCB Project.f3z]
2025-04-11 Added two case versions for the PCB (components at different heights). Included CAD files, STL files, and preview images for both. Enrique Hernando
    [Bnt.stl, Bottom.stl, Capteur_environnementaux_MDRS v32.step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]
2025-06-03 Uploaded second, revised PCB model after identifying design flaws in the original version. Enrique Hernando
    [3D Model.f3d, 3D Model.step, PCB Project.f3z]
2025-06-09 Uploaded third, redone PCB model after identifying desing flaws in the second version. Enrique Hernando
    [PCB Project.f3z]
